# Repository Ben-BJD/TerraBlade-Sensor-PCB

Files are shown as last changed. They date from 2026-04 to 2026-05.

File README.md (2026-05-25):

# 🌱 TerraBlade Sensor - Hardware PCB

 

Project Available on PCBWay (https://www.pcbway.com/project/shareproject/TerraBlade_Ultra_Low_Power_Capacitive_Soil_Moisture_Sensor_8eaea9a2.html)

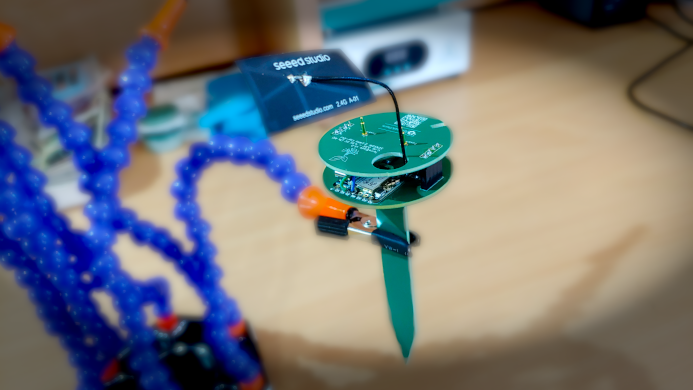
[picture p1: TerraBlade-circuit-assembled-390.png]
Assembled Board

---

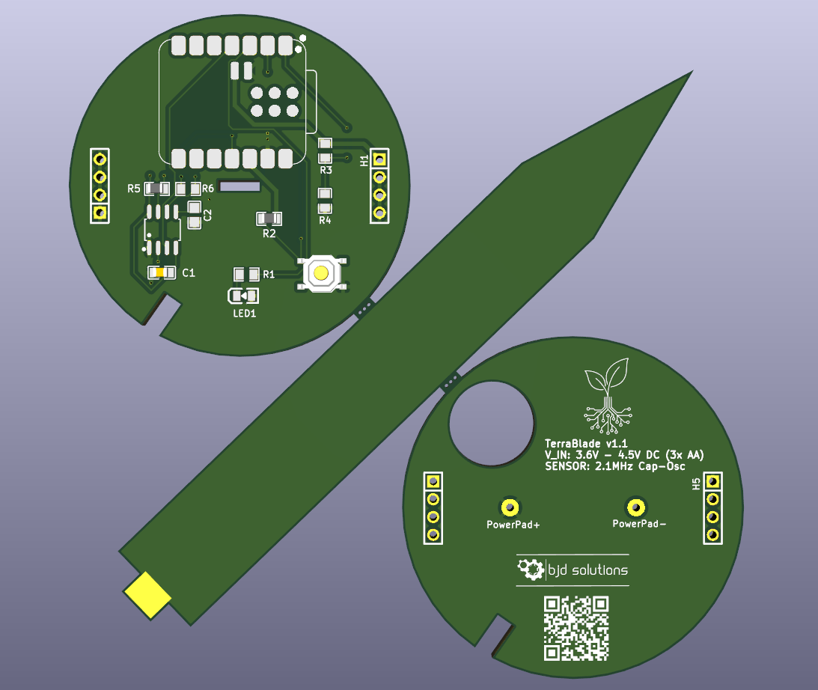
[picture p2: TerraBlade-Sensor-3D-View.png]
TerraBlade 3D Render


**TerraBlade** is a professional-grade, ultra-low-power capacitive soil moisture sensor designed around the Seeed Studio XIAO ESP32-C3. 

This repository contains the complete KiCad 9 hardware design files, manufacturing plots, and mechanical Inkscape references for the PCB assembly. This board is designed using a **"PCBA-Driven"** workflow, meaning the electronics were engineered first, acting as the structural core for a modular 3D-printed enclosure.

Created by [BJD Solutions](https://bj-dehaan-solutions.com.au/).

---

## Key Engineering Features

*   **True Digital Capacitive Sensing:** Ditching the noisy, drifty analog peak-detectors of standard cheap soil sensors. The FR4 PCB blade acts as the timing capacitor for an industrial-grade **TLC555IDR** oscillator. It outputs a raw, clean frequency directly to the ESP32's hardware Pulse Counter (PCNT) for flawless, high-resolution moisture data.
*   **Zero-Leakage "Parasitic" Power:** The 555 timer is powered directly by an ESP32 GPIO pin. The ESP32 wakes up, powers the sensor, takes a reading, and kills the power before going back to sleep. Sensor quiescent current: **0.0µA**.
*   **Panelized 3-in-1 Design:** The **Radio PCB**, **Power Hat**, and **Sensor Blade** are all designed to be manufactured on a single 100x100mm panel connected by mouse-bites to save on fabrication costs.
*   **Mortise & Tenon Assembly:** The Sensor Blade features a custom "tenon" tab that slots perfectly into the main Radio PCB and is soldered directly at a 90-degree angle, requiring zero wires.
*   **Pogo-Pin Power Hat:** Handles the mechanical shear force of a plunging outdoor sensor by using through-hole Pogo Pins (spring-loaded contacts) rather than weak SMD conical springs.
*   **Low-Voltage Optimized:** Features an ultra-efficient 573nm Yellow-Green LED that requires only ~2.0V to light up. It will reliably flash in "Config Mode" even when the 3x AA batteries are nearly dead. Includes a precision 1% 220kΩ voltage divider for highly accurate battery monitoring.

---

## 📂 Repository Structure

*   Full KiCad 9 project files (`.kicad_pro`, `.kicad_sch`, `.kicad_pcb`).
*   Ready-to-order plot files, drill files, and the solder paste stencil map.
*   High-resolution PDF exports of the schematic and PCB layers.
*   Original Inkscape (`.svg`) files used to perfectly calculate the complex `Edge.Cuts` curves, alignment notches, and Mortise & Tenon joints.

---

## 🛠️ Assembly & Manufacturing Notes

If you are ordering these boards from a fabricator please note the following:

1.  **Thickness:** Order in standard **1.6mm FR4**. The Mortise and Tenon slot on the Radio PCB is routed to exactly 1.7mm to provide a perfect slip-fit for 1.6mm thick material.
2.  **Solder Mask is Mandatory:** Do NOT expose the copper on the Sensor Blade. The blade relies on the green Solder Mask to act as a waterproof dielectric barrier. Exposing the copper to wet soil will cause rapid galvanic corrosion and destroy the sensor.
3.  **Keyway Notches:** The Radio PCB and Power Hat feature an 8-o'clock alignment notch. This is an asymmetrical keyway designed to interface with a matching rail in the future 3D-printed enclosure, preventing the board from twisting or being inserted backward.
4.  **Solder Paste Stencil:** The `F.Paste` layer has been custom-tailored to remove paste from the structural Mortise & Tenon joints, allowing for clean, manual fillet soldering without bridging.

---

## 🛒 BOM Highlights (LCSC)

The full [BOM](BOM.csv) is included and can be generated from the KiCad schematic, here are the critical components used in this design:

*   **Microcontroller:** Seeed Studio XIAO ESP32-C3
*   **Timer IC:** TLC555IDR (Industrial Temp Range: -40°C to 85°C) - *LCSC: C6987*
*   **Pogo Pins (Power Contacts):** CHIN-BAN PG1000-01-010P (1A Through-Hole) - *LCSC: C49451494*
*   **Config LED:** TUOZHAN 0805 Yellow-Green 573nm (1.8V-2.4V) - *LCSC: C688885*
*   **Tactile Switch:** TS-1187A-B-A-B (4-pin SMD) - *LCSC: C318884*

---

## 📄 License

This hardware design is open-source. Feel free to build it, mod it, and plant it! 
Designed by [BJD Solutions](https://bj-dehaan-solutions.com.au/).

---

## Schematic:

[PDF Version](TerraBlade-Sensor-Schematic.pdf)

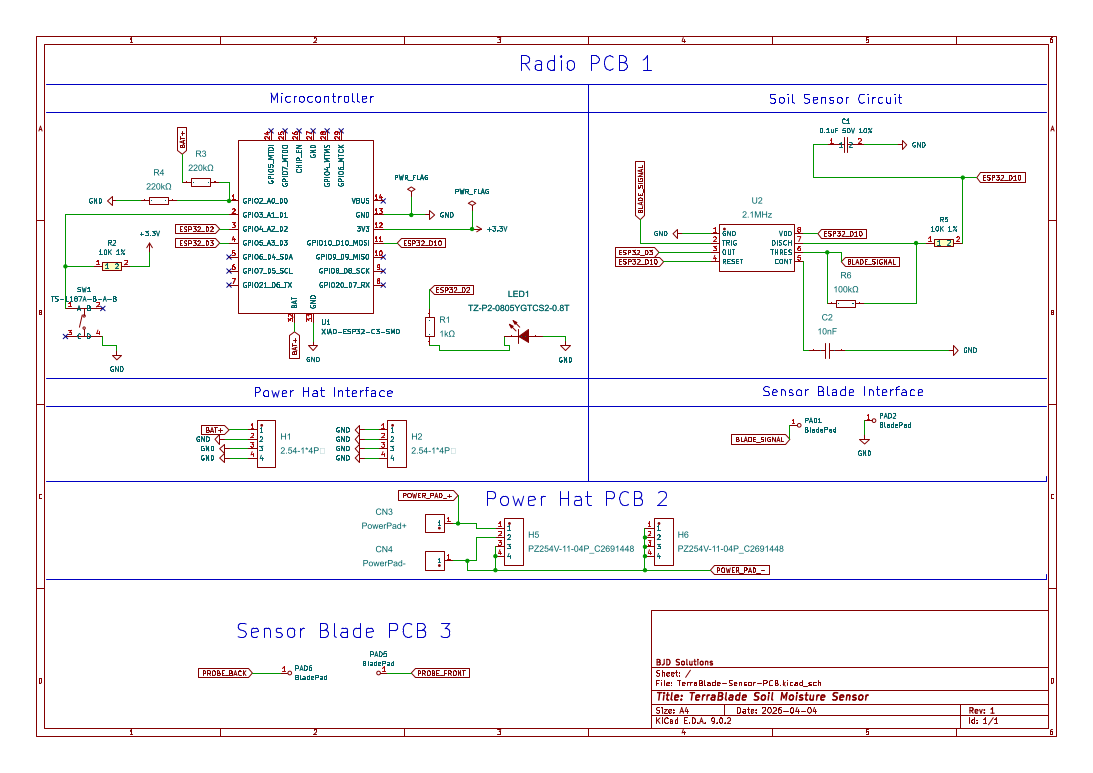
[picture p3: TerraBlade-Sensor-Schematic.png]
Board schematic


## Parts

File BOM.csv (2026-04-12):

Reference | Qty | Value | DNP | Exclude from BOM | Exclude from Board | Footprint | Datasheet | Supplier Part
C1 | 1 | 0.1uF 50V 10% |  |  |  | easyeda2kicad:C0805 | https://lcsc.com/product-detail/Multilayer-Ceramic-Capacitors-MLCC-SMD-SMT_C0805B104K500NT_C476766.html | C476766
C2 | 1 | 10nF |  |  |  | Custom:C0805 | https://www.lcsc.com/product-detail/C83170.html | C83170
CN3 | 1 | PowerPad+ |  |  |  | Custom:TESTPOINT-SMD_BD2.0-D1.0-Custom | https://www.lcsc.com/product-detail/C49451494.html | C49451494
CN4 | 1 | PowerPad- |  |  |  | Custom:TESTPOINT-SMD_BD2.0-D1.0-Custom | https://www.lcsc.com/product-detail/C49451494.html | C49451494
H1,H2 | 2 | 2.54-1*4P母 |  |  |  | Custom:HDR-TH_4P-P2.54-V-F | https://www.lcsc.com/product-detail/C2718488.html | C2718488
H5,H6 | 2 | PZ254V-11-04P_C2691448 |  |  |  | Custom:HDR-TH_4P-P2.54-V-M | https://www.lcsc.com/product-detail/C2691448.html | C2691448
LED1 | 1 | TZ-P2-0805YGTCS2-0.8T |  |  |  | Custom:LED0805-R-RD_GREEN | https://www.lcsc.com/product-detail/C688885.html | C688885
PAD1,PAD2,PAD5,PAD6 | 4 | BladePad |  | Excluded from BOM |  | Custom:BladePad_SMD
R1 | 1 | 1kΩ |  |  |  | Custom:R0805 | https://www.lcsc.com/product-detail/C2907295.html | C2907295
R2,R5 | 2 | 10K 1% |  |  |  | easyeda2kicad:R0805 | https://lcsc.com/product-detail/Chip-Resistor-Surface-Mount-UniOhm_10KR-1002-1_C17414.html | C17414
R3,R4 | 2 | 220kΩ |  |  |  | Custom:R0805 | https://www.lcsc.com/product-detail/C17556.html | C17556
R6 | 1 | 100kΩ |  |  |  | Custom:R0805 | https://www.lcsc.com/product-detail/C149504.html | C149504
SW1 | 1 | TS-1187A-B-A-B |  |  |  | easyeda2kicad:SW-SMD_4P-L5.1-W5.1-P3.70-LS6.5-TL_H1.5 | https://lcsc.com/product-detail/Tactile-Switches_XKB-Enterprise-TS-1187-B-A-A_C318884.html | C318884
U1 | 1 | XIAO-ESP32-C3-SMD |  |  |  | SEED:XIAO-ESP32-C3-SMD | https://wiki.seeedstudio.com/XIAO_ESP32C3_Getting_Started/
U2 | 1 | 2.1MHz |  |  |  | Custom:SOIC-8_L4.9-W3.9-P1.27-LS6.0-BL | https://www.lcsc.com/product-detail/C6987.html | C6987

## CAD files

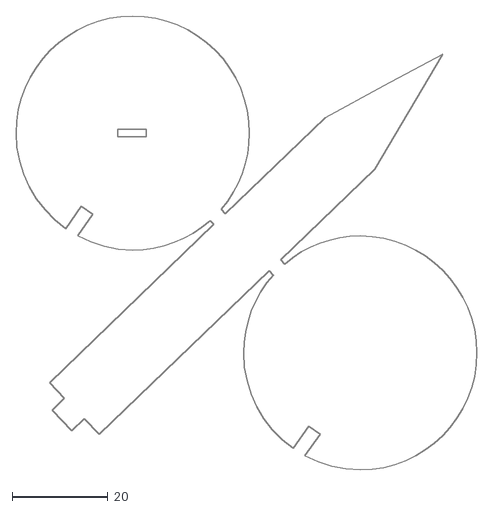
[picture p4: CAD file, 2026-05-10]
Blade-Design.dxf
96.4 x 95.0

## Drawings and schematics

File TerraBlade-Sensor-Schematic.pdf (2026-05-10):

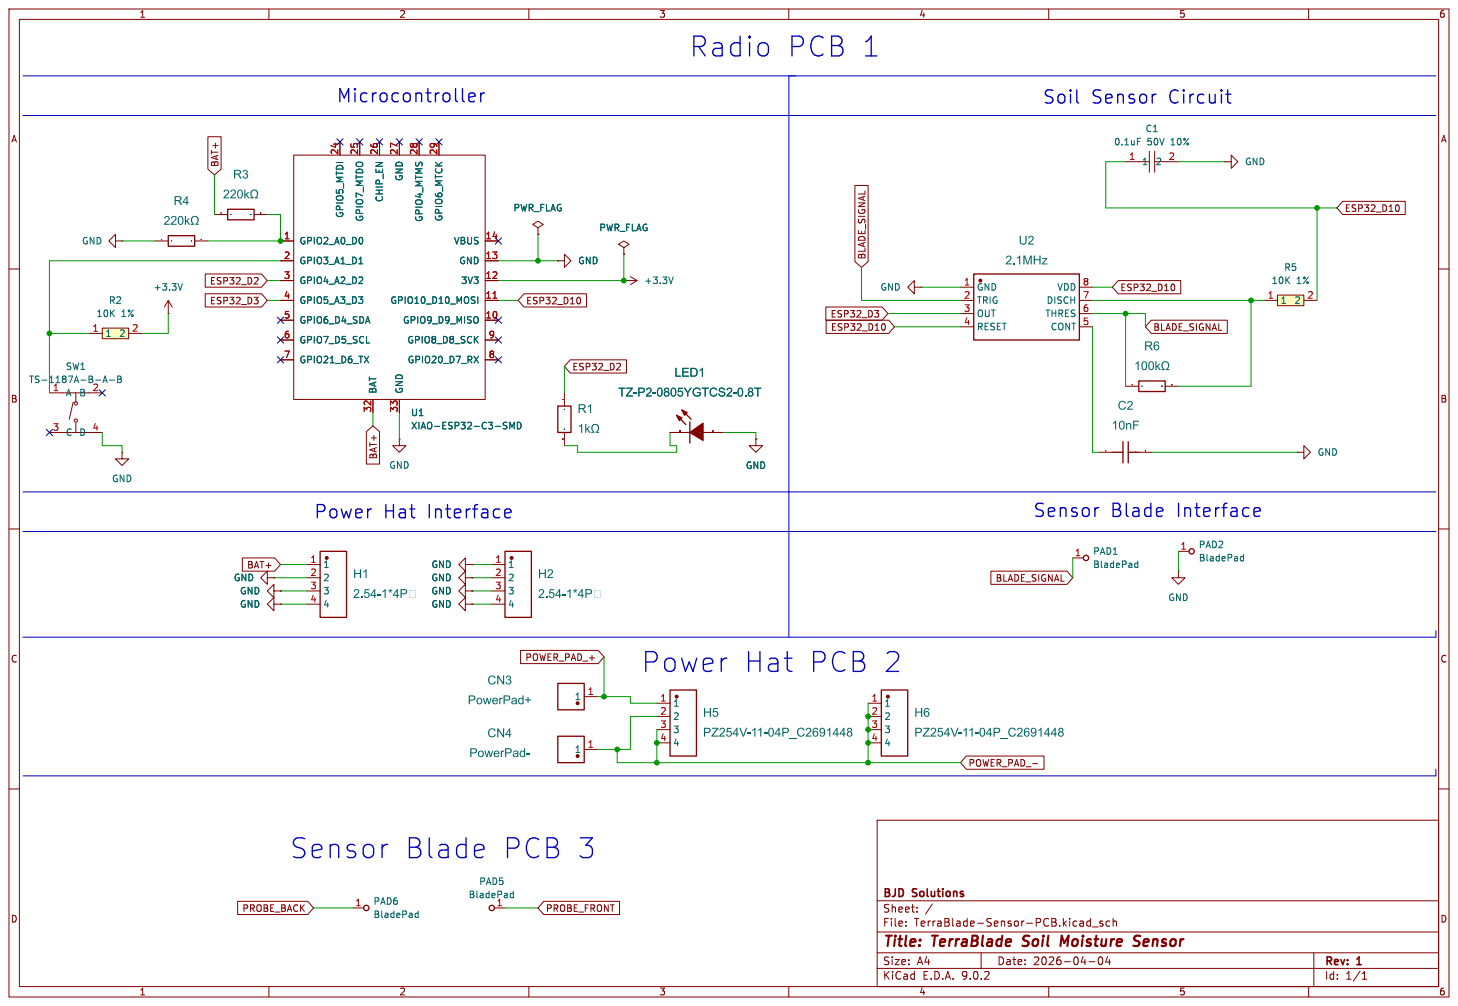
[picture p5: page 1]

Id: 1/1 Title: TerraBlade Soil Moisture Sensor File: TerraBlade-Sensor-PCB.kicad_sch Sheet: / BJD Solutions

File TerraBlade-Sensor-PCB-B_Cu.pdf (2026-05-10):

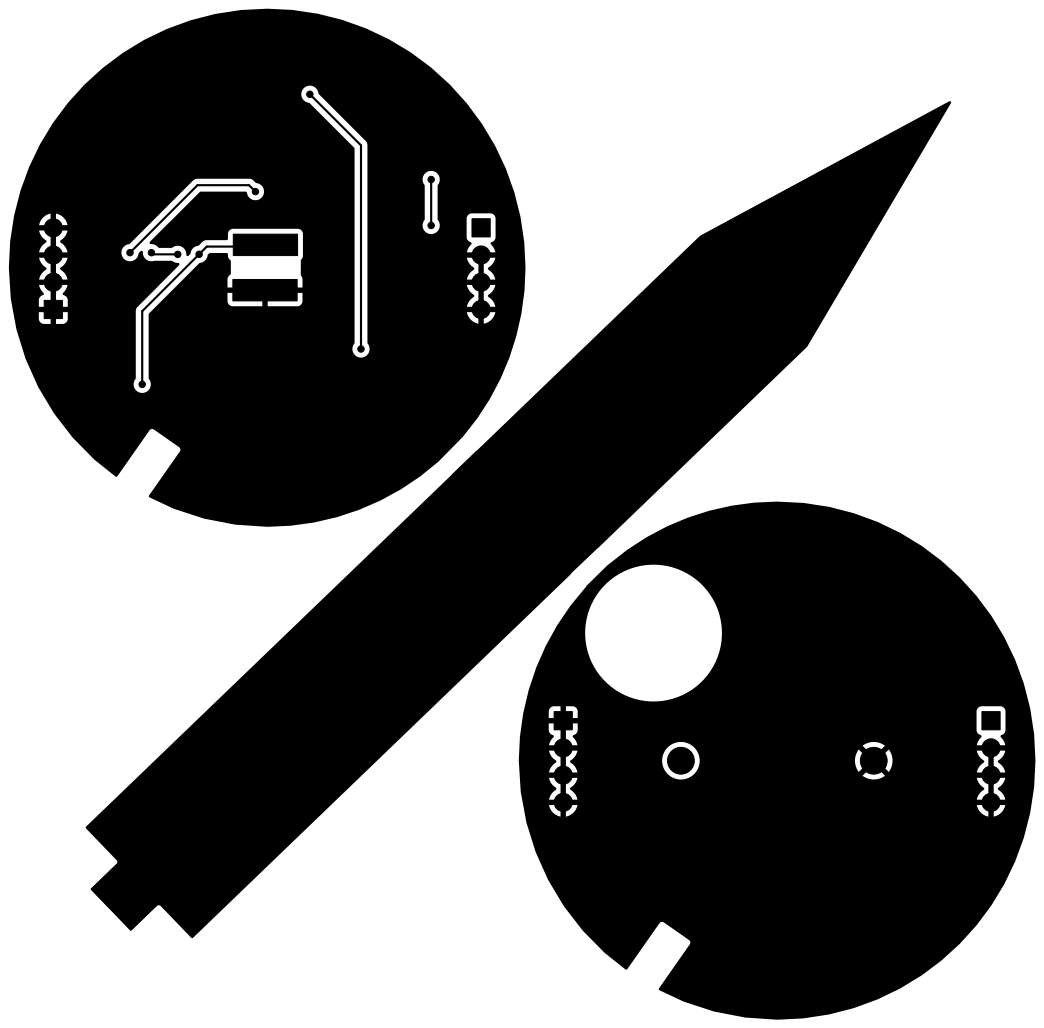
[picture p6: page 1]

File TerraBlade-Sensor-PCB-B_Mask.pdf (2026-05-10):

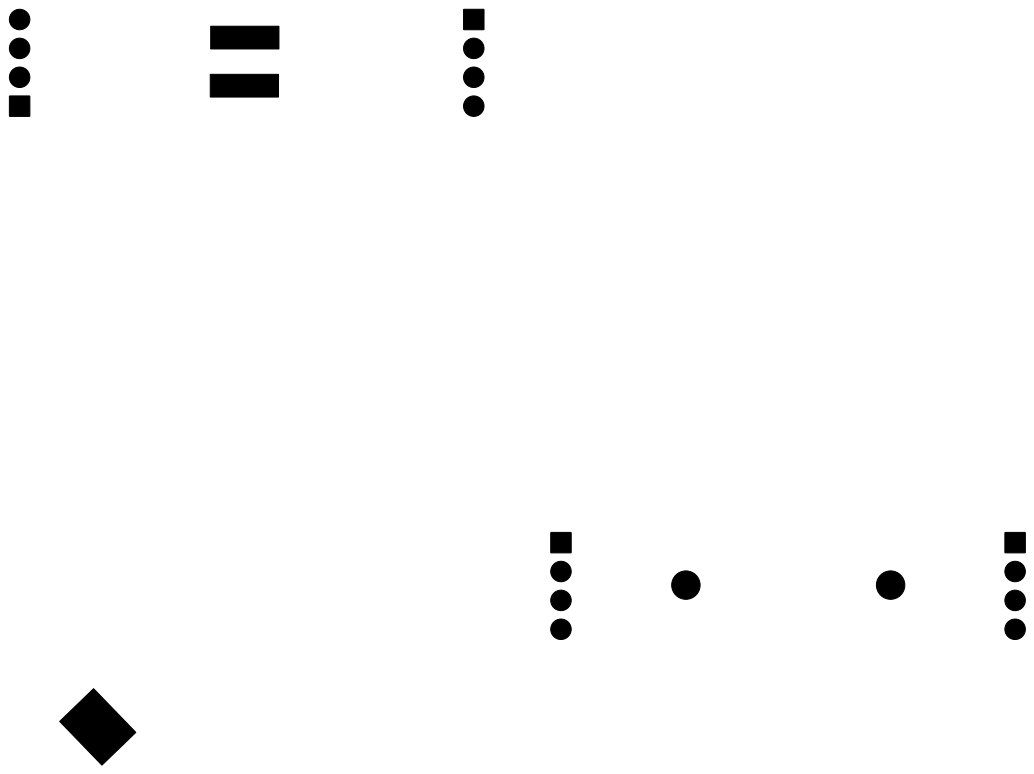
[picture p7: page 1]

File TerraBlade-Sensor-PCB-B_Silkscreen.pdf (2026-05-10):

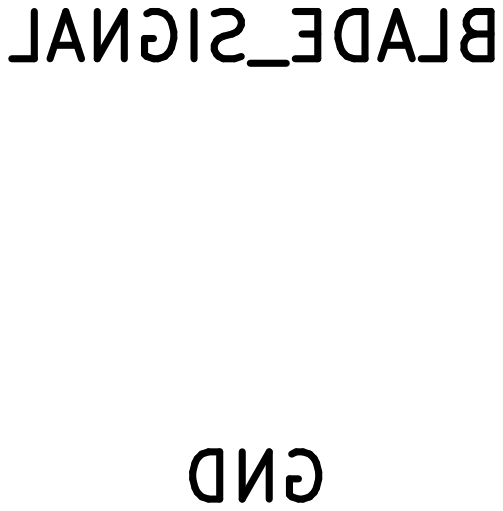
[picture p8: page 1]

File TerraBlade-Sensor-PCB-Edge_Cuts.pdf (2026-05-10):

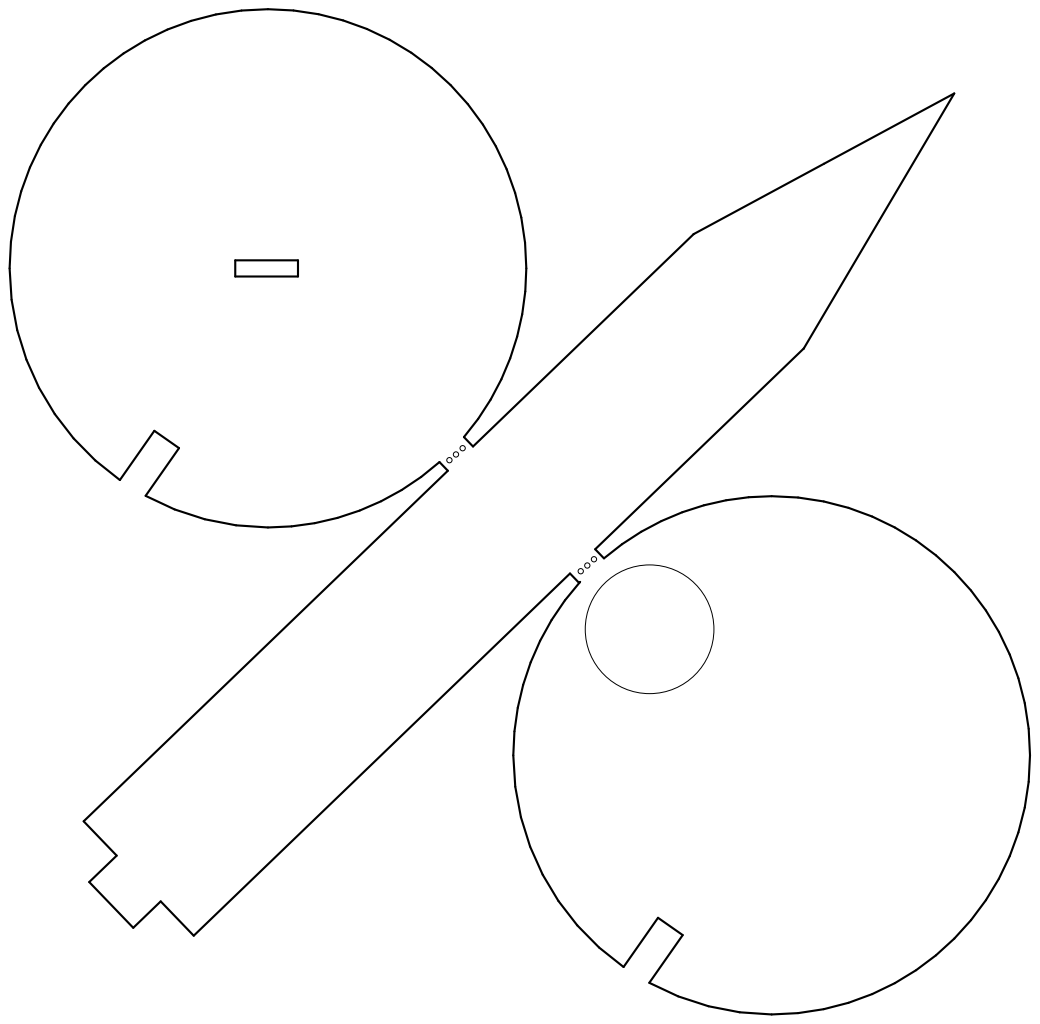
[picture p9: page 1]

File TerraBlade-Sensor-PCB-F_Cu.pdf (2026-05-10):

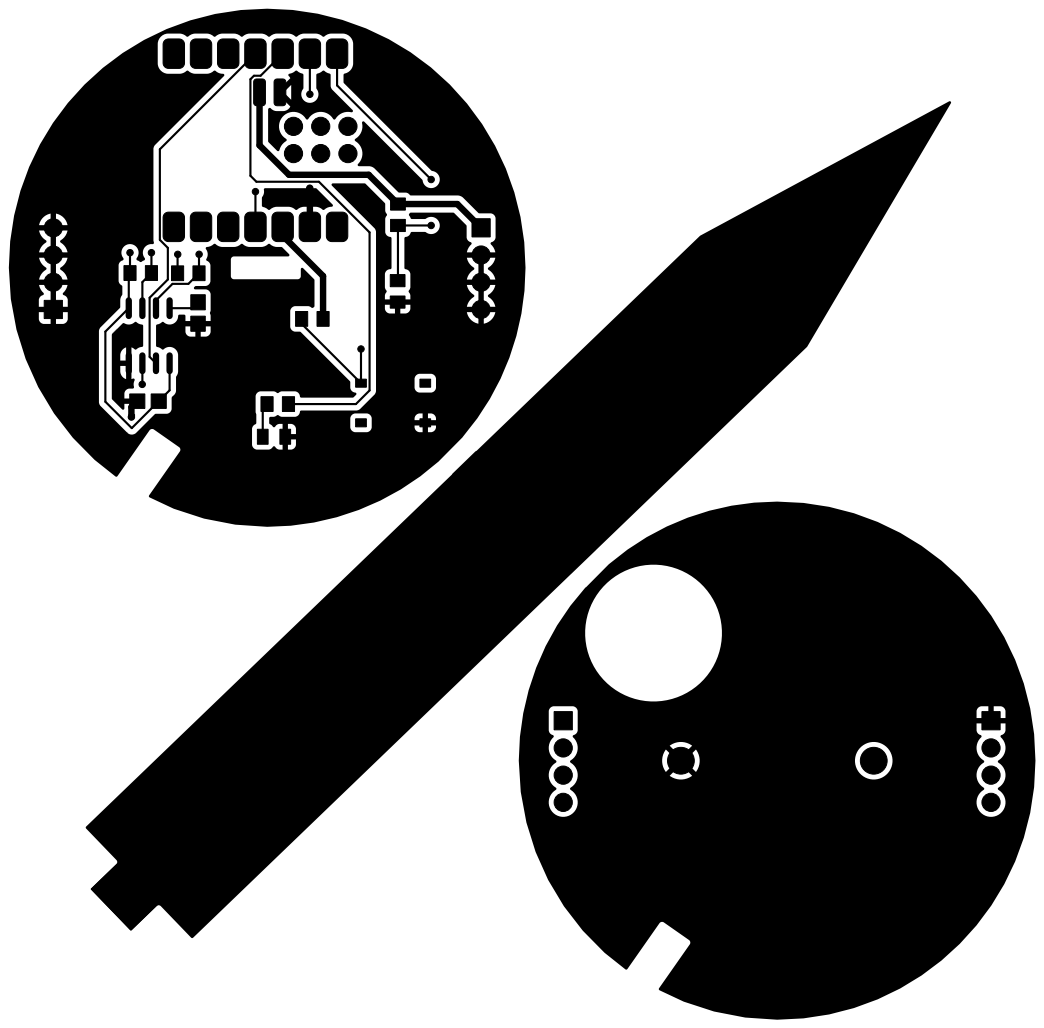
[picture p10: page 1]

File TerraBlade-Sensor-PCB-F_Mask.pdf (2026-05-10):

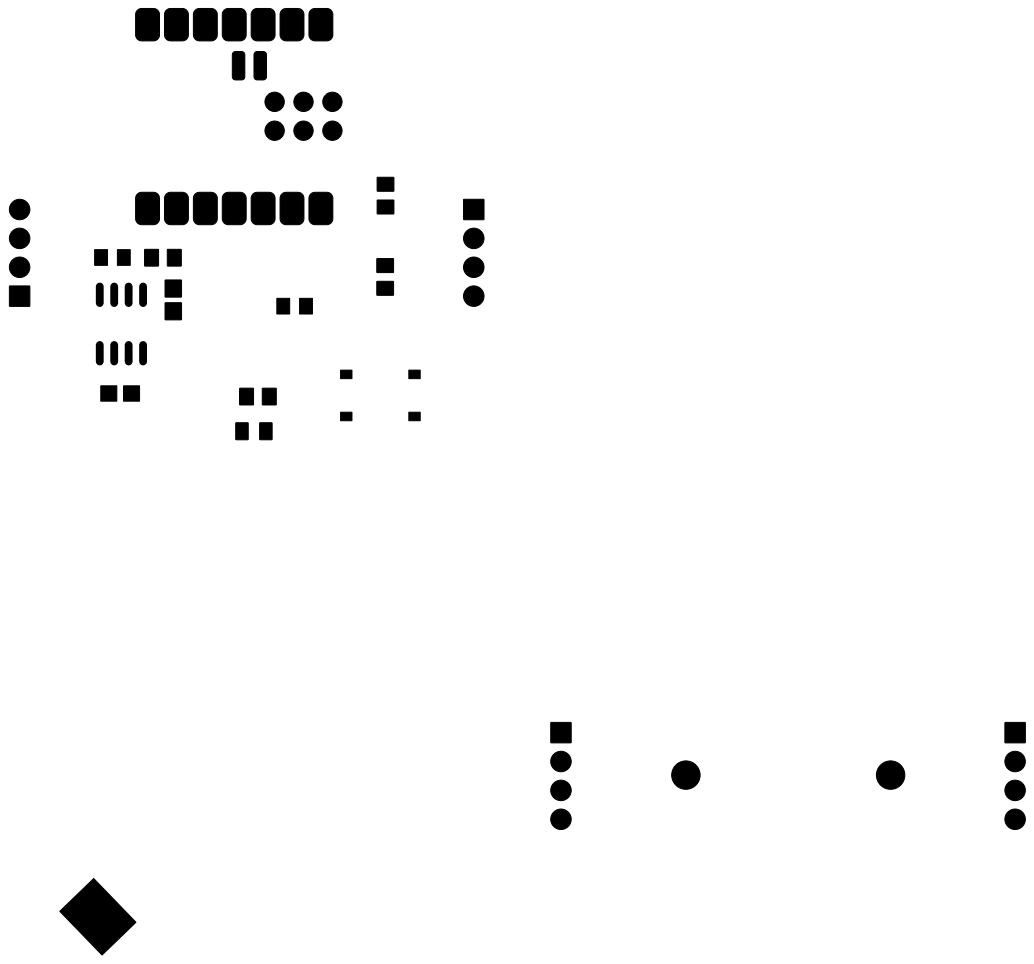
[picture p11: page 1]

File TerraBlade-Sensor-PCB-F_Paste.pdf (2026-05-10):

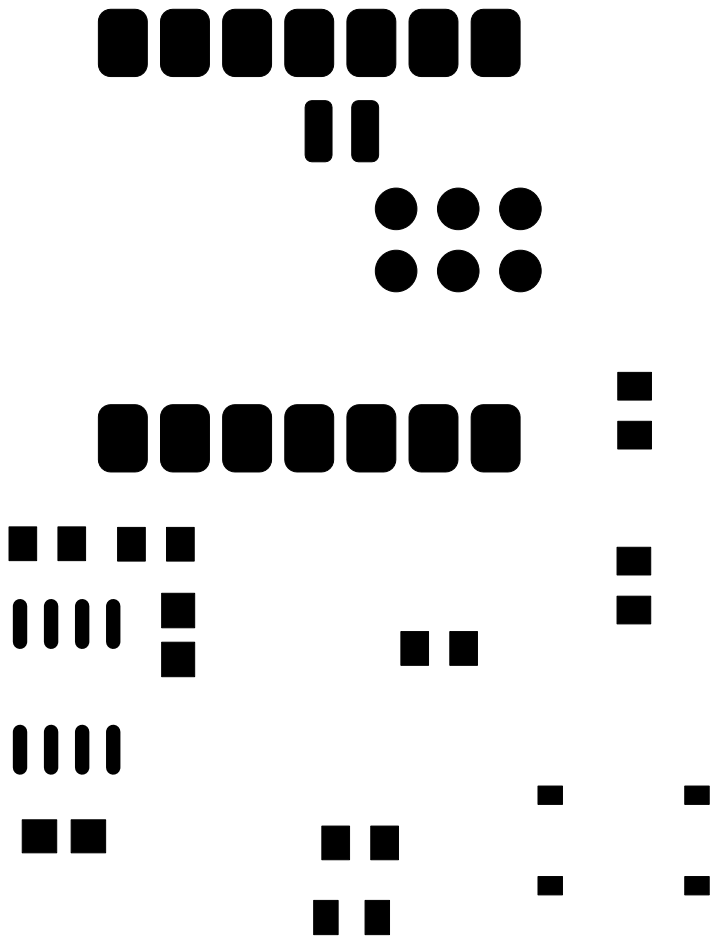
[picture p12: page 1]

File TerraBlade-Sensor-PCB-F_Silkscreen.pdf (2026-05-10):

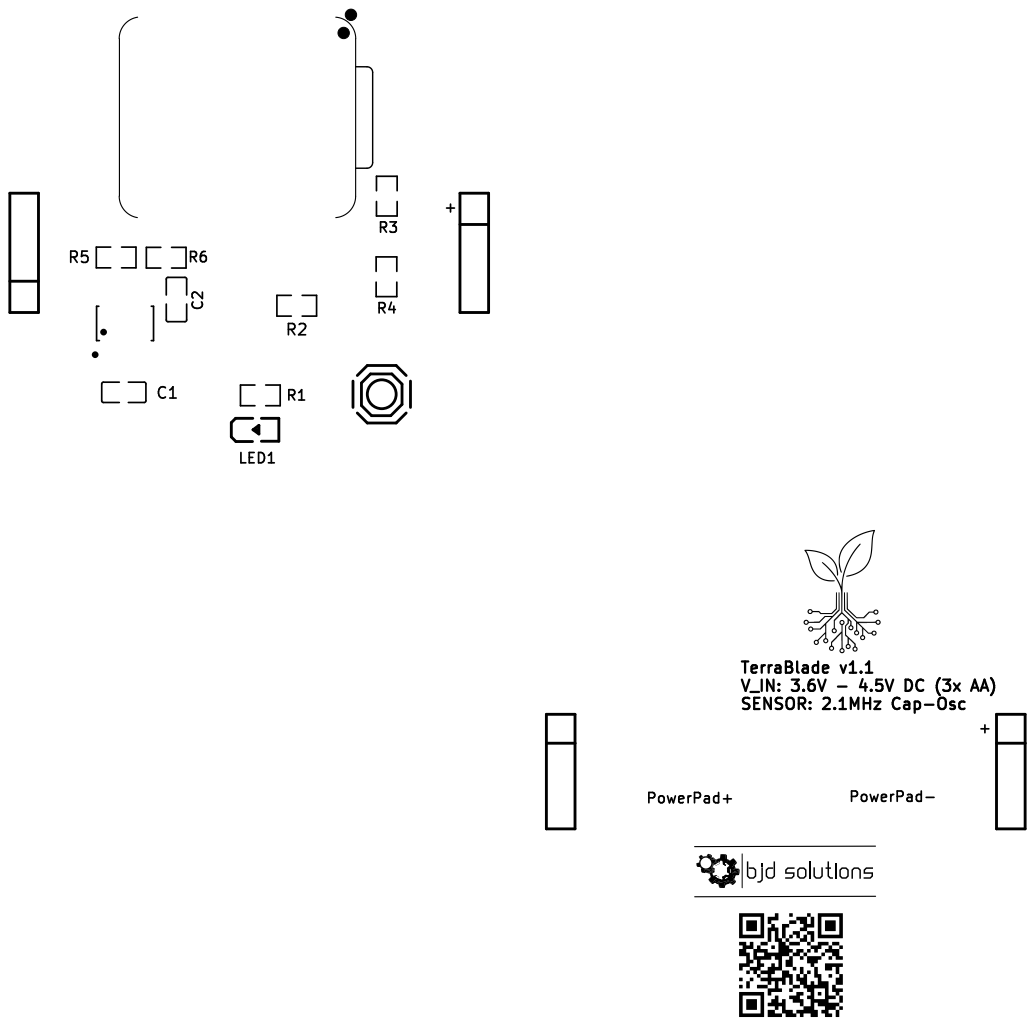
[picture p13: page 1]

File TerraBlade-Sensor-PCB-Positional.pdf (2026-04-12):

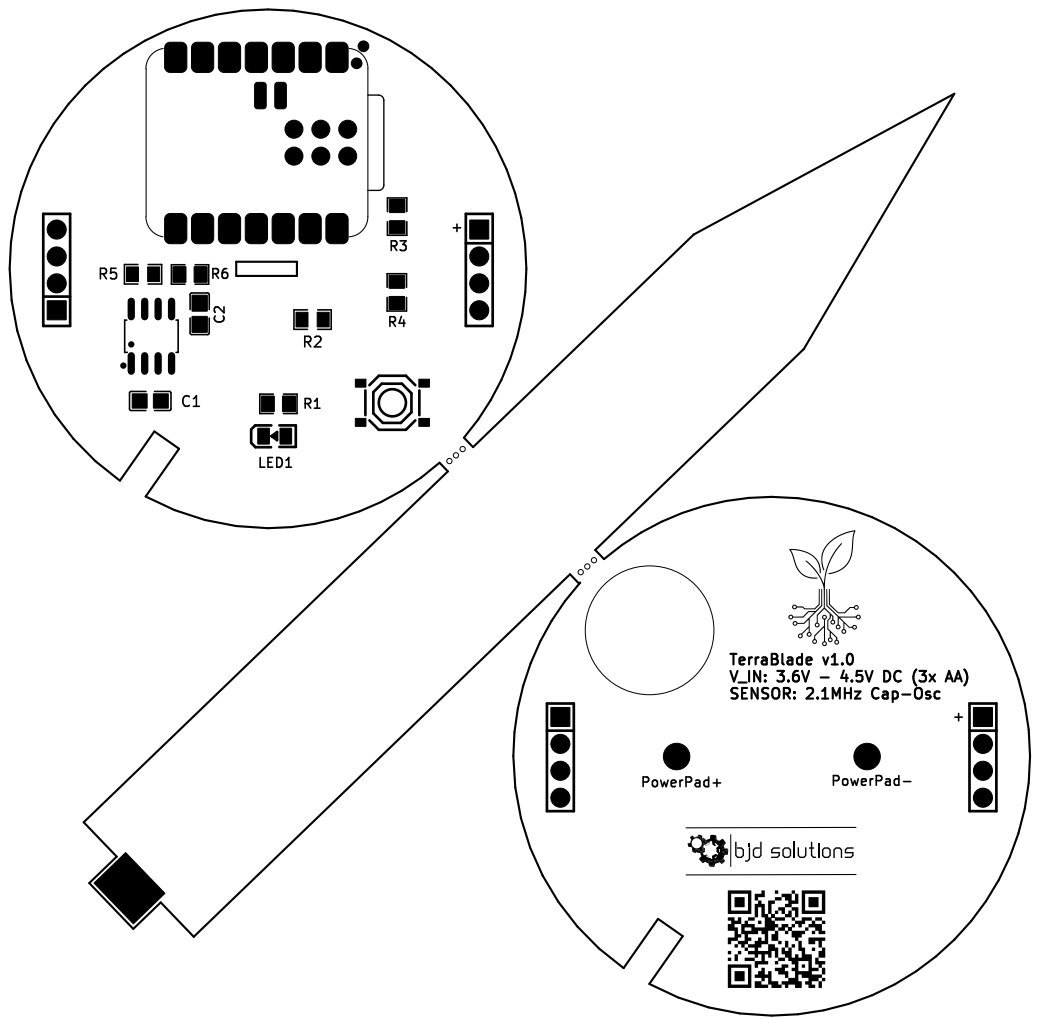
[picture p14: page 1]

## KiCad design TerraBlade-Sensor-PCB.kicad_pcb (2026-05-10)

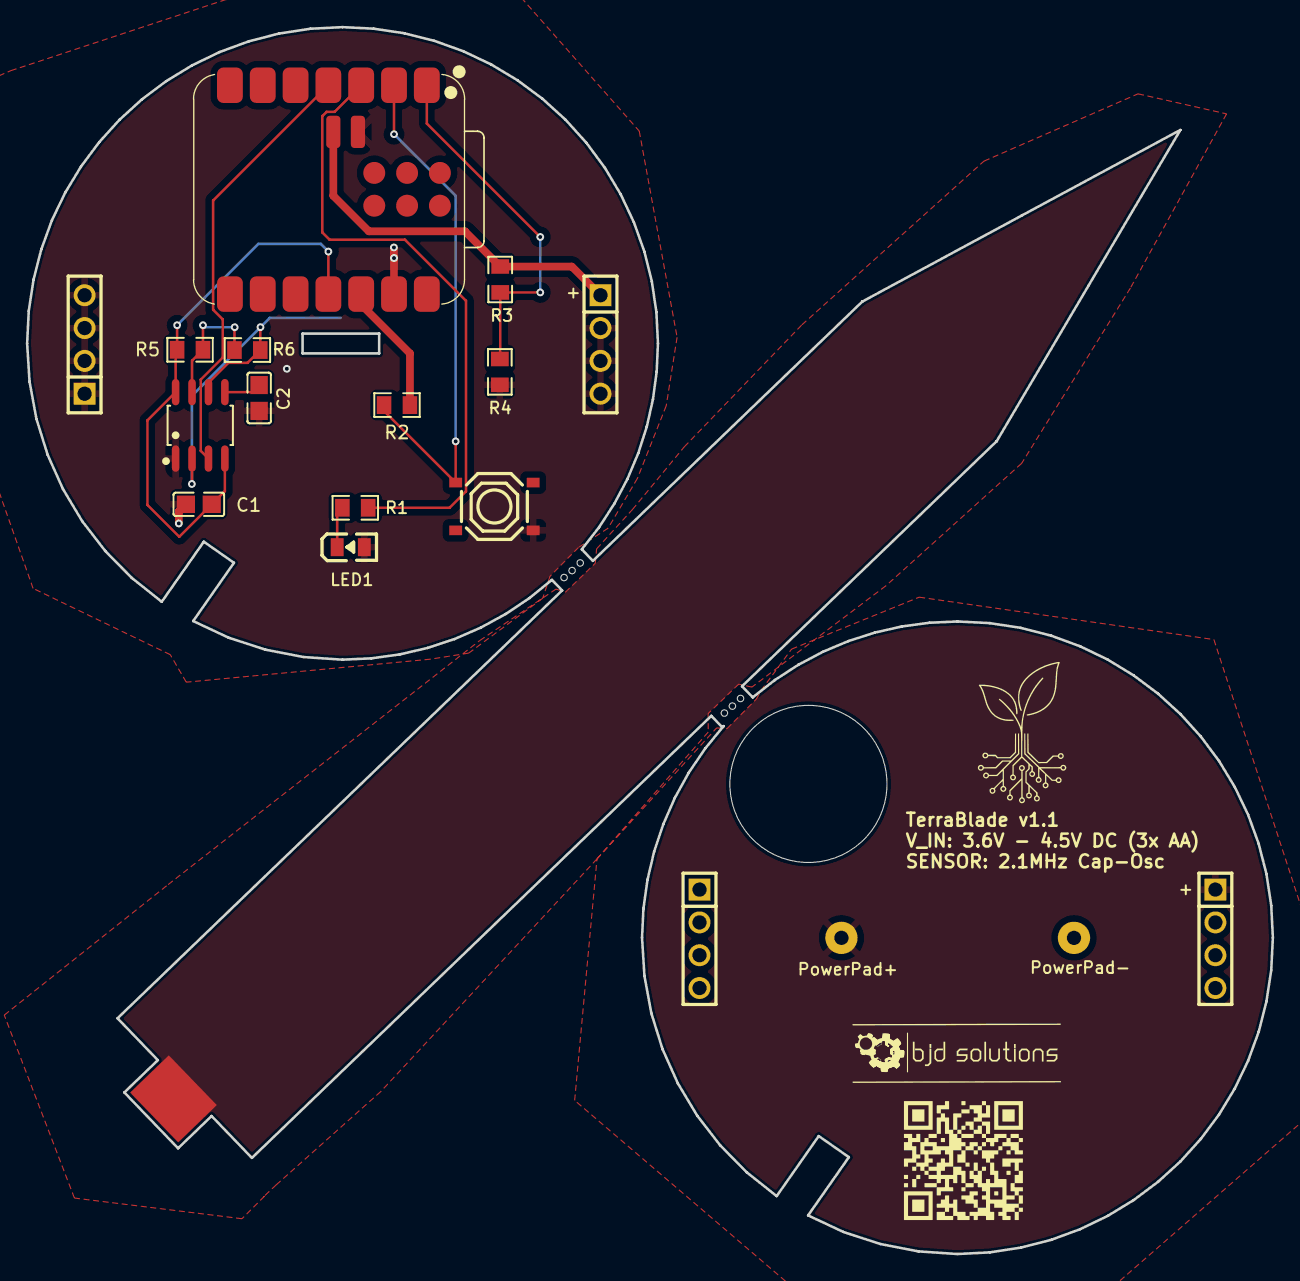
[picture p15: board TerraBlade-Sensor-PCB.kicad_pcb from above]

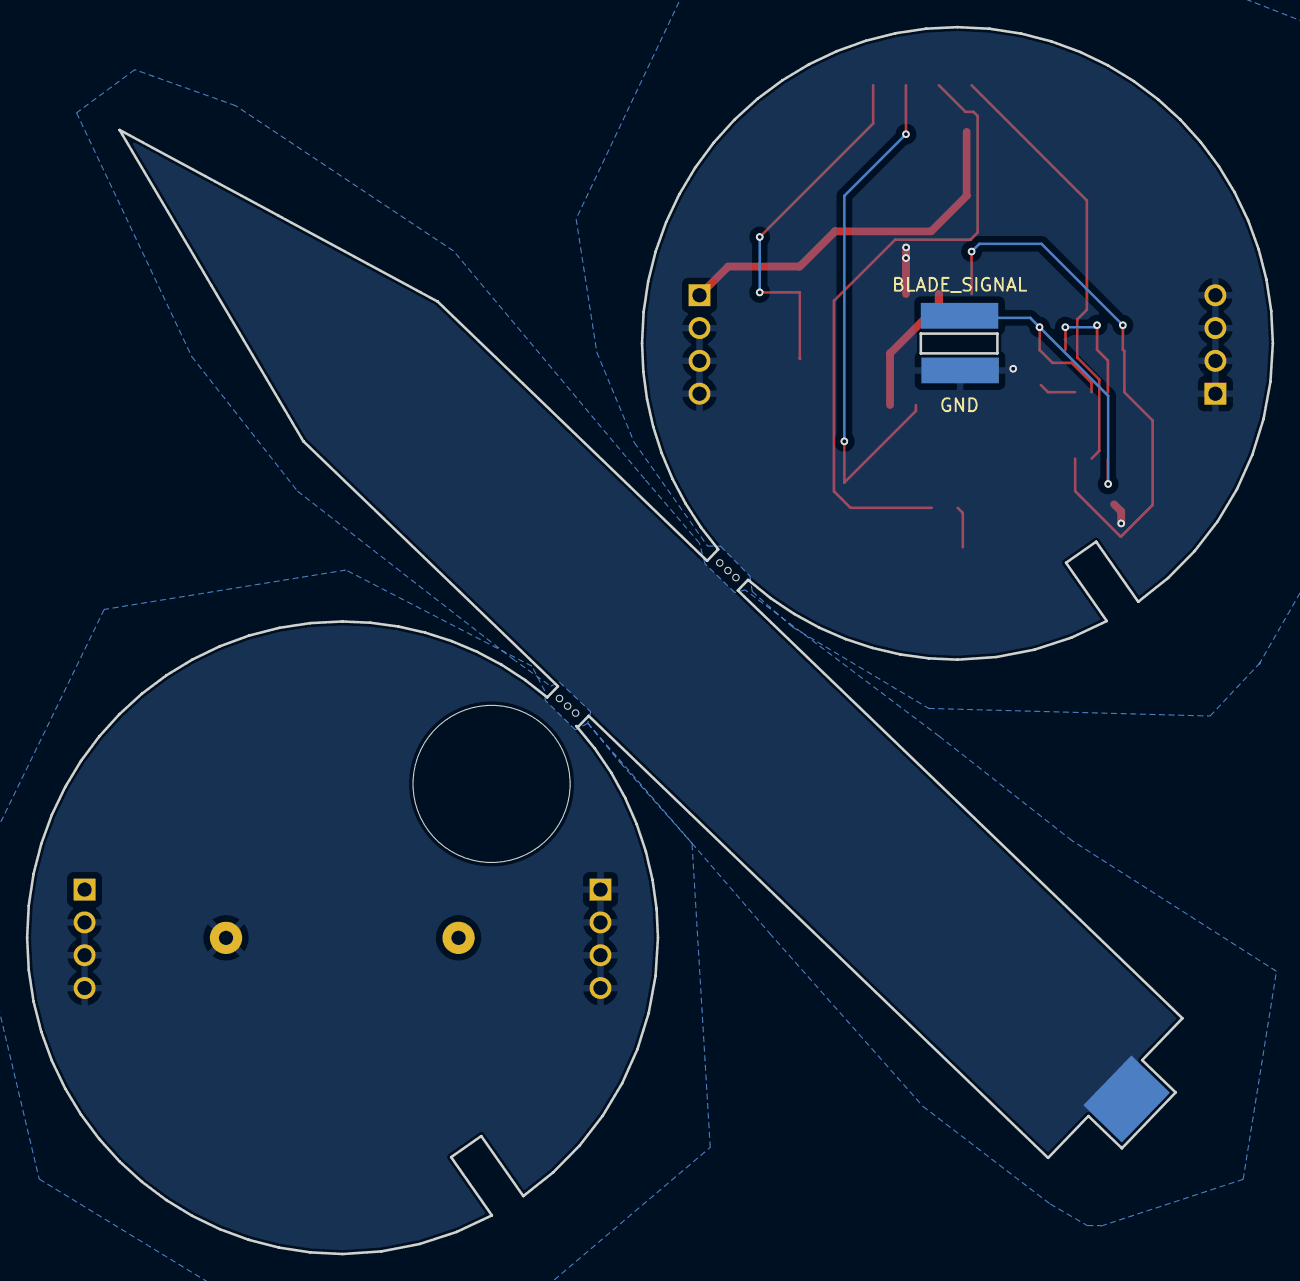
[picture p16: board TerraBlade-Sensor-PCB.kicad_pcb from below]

Board: 2 copper layers, 96.4 x 95.0 mm, 22 parts (3 on the bottom side), 14 nets.

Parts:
+: PZ254V-11-04P_C2691448; HDR-TH_4P-P2.54-V-M
+#2: 2.54-1*4P母; HDR-TH_4P-P2.54-V-F
BLADE_SIGNAL: BladePad; BladePad_SMD
C1: 0.1uF 50V 10%; C0805
C2: 10nF; C0805
CN3: PowerPad+; TESTPOINT-SMD_BD2.0-D1.0-Custom
CN4: PowerPad-; TESTPOINT-SMD_BD2.0-D1.0-Custom
GND: BladePad; BladePad_SMD
H2: 2.54-1*4P母; HDR-TH_4P-P2.54-V-F
H6: PZ254V-11-04P_C2691448; HDR-TH_4P-P2.54-V-M
LED1: TZ-P2-0805YGTCS2-0.8T; LED0805-R-RD_GREEN
PAD5, PAD6: BladePad; BladePad_SMD
R1: 1kΩ; R0805
R2, R5: 10K 1%; R0805
R3, R4: 220kΩ; R0805
R6: 100kΩ; R0805
SW1: TS-1187A-B-A-B; SW-SMD_4P-L5.1-W5.1-P3.70-LS6.5-TL_H1.5
U1: XIAO-ESP32-C3-SMD
U2: 2.1MHz; SOIC-8_L4.9-W3.9-P1.27-LS6.0-BL

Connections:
+3.3V: R2.2, U1.12 (3V3)
BAT+: +#2.1, R3.1, U1.32 (BAT)
BLADE_SIGNAL: BLADE_SIGNAL.1, R6.1, U2.2 (TRIG), U2.6 (THRES)
ESP32_D2: R1.1, U1.3 (GPIO4_A2_D2)
ESP32_D3: U1.4 (GPIO5_A3_D3), U2.3 (OUT)
ESP32_D10: C1.1, R5.2, U1.11 (GPIO10_D10_MOSI), U2.4 (RESET), U2.8 (VDD)
GND: +#2.2, +#2.3, +#2.4, C1.2, C2.2, GND.1, H2.1, H2.2, H2.3, H2.4, LED1.1 (A), R4.1, SW1.4 (D), U1.13 (GND), U1.33 (GND), U2.1 (GND)
unnamed: LED1.2 (K), R1.2
unnamed: R2.1, SW1.1 (A), U1.2 (GPIO3_A1_D1)
unnamed: R3.2, R4.2, U1.1 (GPIO2_A0_D0)
unnamed: C2.1, U2.5 (CONT)
unnamed: R5.1, R6.2, U2.7 (DISCH)
POWER_PAD_+: +.1, CN3.1
POWER_PAD_-: +.2, +.3, +.4, CN4.1, H6.1, H6.2, H6.3, H6.4

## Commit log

2026-04-11 PCB Design
    [Blade-Design.dxf, TerraBlade-Sensor-PCB.kicad_pcb, TerraBlade-Sensor-PCB.kicad_sch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]
2026-04-12 PCB Layout
    [BOM.csv, TerraBlade-Sensor-PCB.csv, TerraBlade-Sensor-PCB.kicad_pcb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]
2026-05-10 Remap Digital Pins (Don't use strapping pins) / Increase size of the mortise tenon slot
    [Blade-Design.dxf, TerraBlade-Sensor-PCB.kicad_pcb, TerraBlade-Sensor-PCB.kicad_sch]
2026-05-10 Silk Screen changes
    [TerraBlade-Sensor-PCB.kicad_pcb]
